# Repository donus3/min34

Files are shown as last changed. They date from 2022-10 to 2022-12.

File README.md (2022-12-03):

# min34

A minimal split keyboard with 34 keys

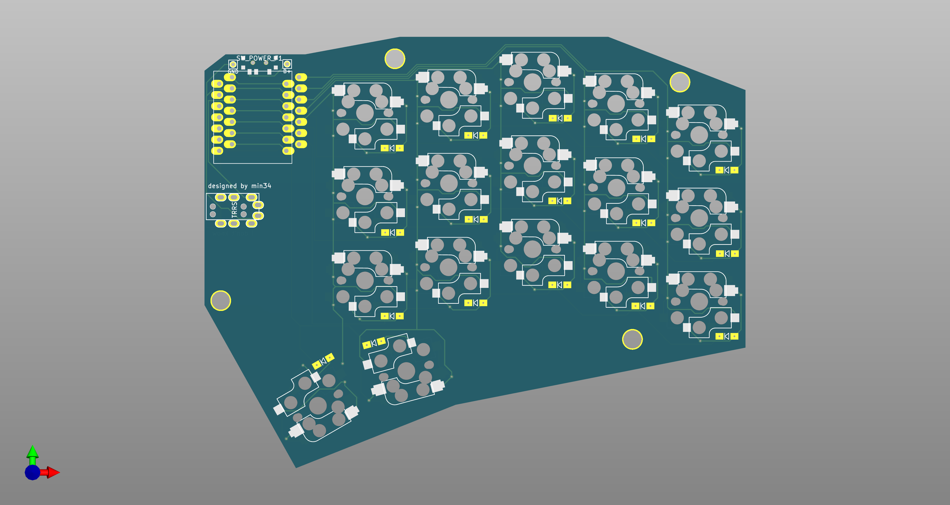
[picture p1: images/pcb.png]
pcb


## Features
 - 34 keys (inspired by Sweep)
 - Support a hotswap switch both MX and Kailh low profile style (inspired by SofleKeyboard)
 - Using seeed studio XIAO series microcontroller which means both wire and wireless are available
 - Support a battery switch on/off if Bluetooth microcontroller is used
 - The PCB is reversible
 - No reset button (it's already on the microcontroller)

I don't focus on adding more features like an OLED display or a rotary encoder because I would like to keep it as simple as possible and I personally
don't use them in my daily life (as a programmer).

## Compnents
 - 2x PCBs (for left and right)
 - 2x seeed studio XIAO compatible boards.
 - 34 switches of MX or Kailh low profile style
 - 34 kailh switch sockets (MX or Kailh low profile)
 - 34 diodes 1N4148W
 - 34 keycaps
 - (optional; only for battery support) 2x power switches (MSK 12C02)
 - (optional; only for wire support) 2x TRRS connectors
 - (optional; only for wire support) 1x TRRS cable
 - 1 USB Cable

## Firmware
Please refer to [min34 zmk config](./firmware)

## Thanks to
 - [SofleKeyboard](https://github.com/josefadamcik/SofleKeyboard)
 - [crkbd](https://github.com/foostan/crkbd)
 - [Slice36](https://github.com/MReavley/Slice36)
 - [Sweep](https://github.com/davidphilipbarr/Sweep)
 - Seeed xiao nrf52840 mcu: https://www.seeedstudio.com/Seeed-XIAO-BLE-nRF52840-p-5201.html
 - Seeed Fusion PCBA service: https://www.seeedstudio.com/pcb-assembly.html
 - Seeed Fusion DIY Mechanical Keyboard contest: https://www.seeedstudio.com/seeed-fusion-diy-xiao-mechanical-keyboard-contest.html

## Gallery

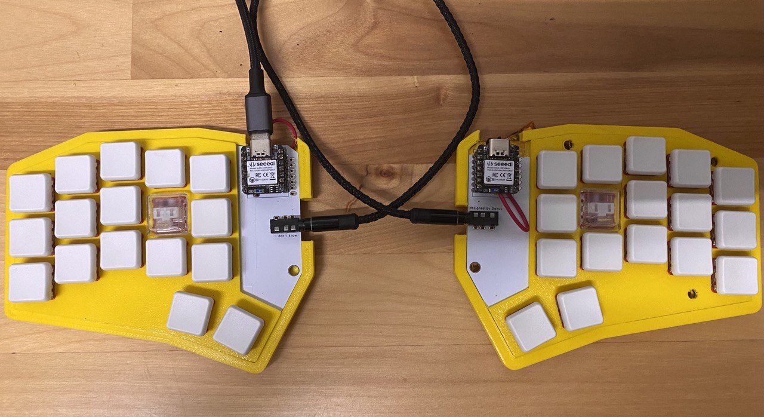
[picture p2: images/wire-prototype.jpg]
min34-wire


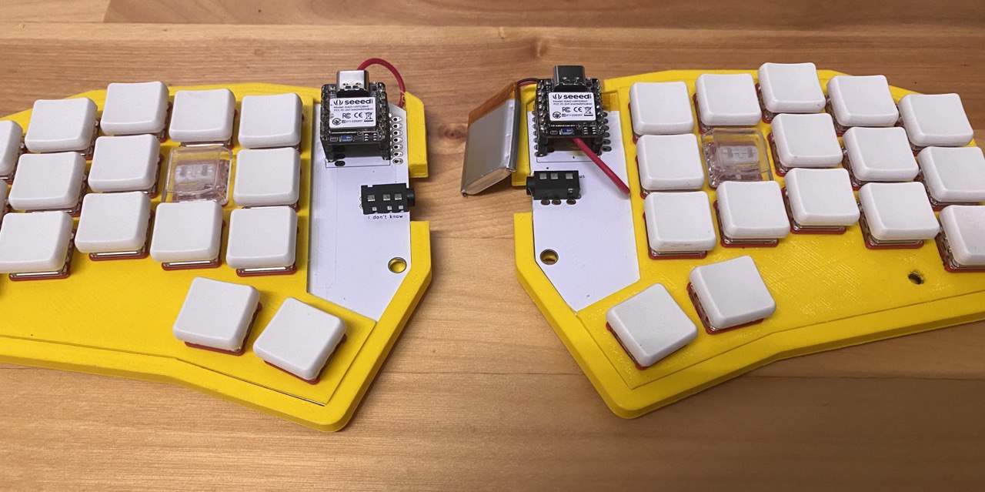
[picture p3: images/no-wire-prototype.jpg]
min34-no-wire


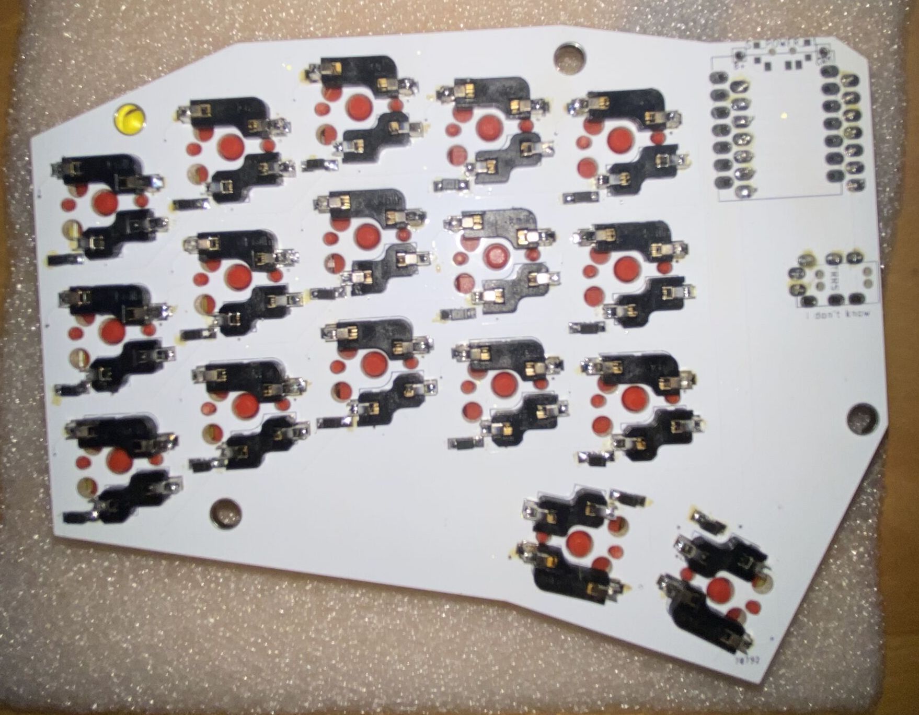
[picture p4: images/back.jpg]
min34-back


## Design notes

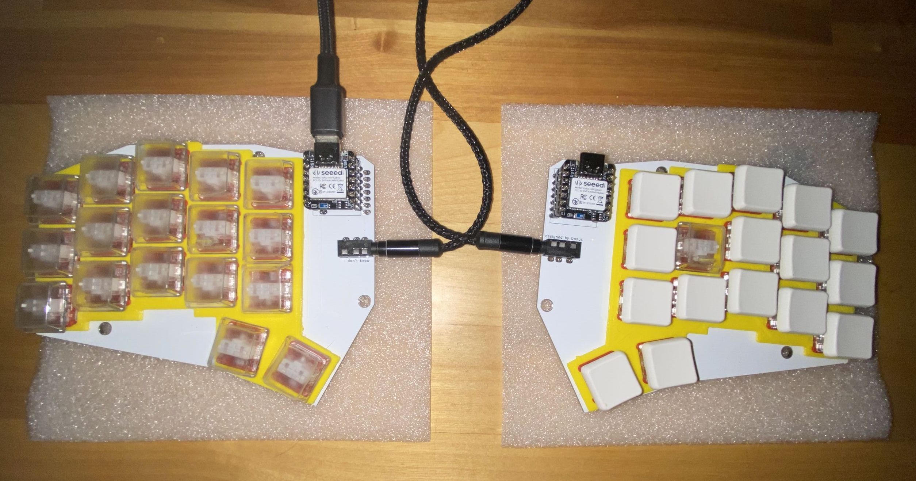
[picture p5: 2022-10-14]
images/wire.jpg

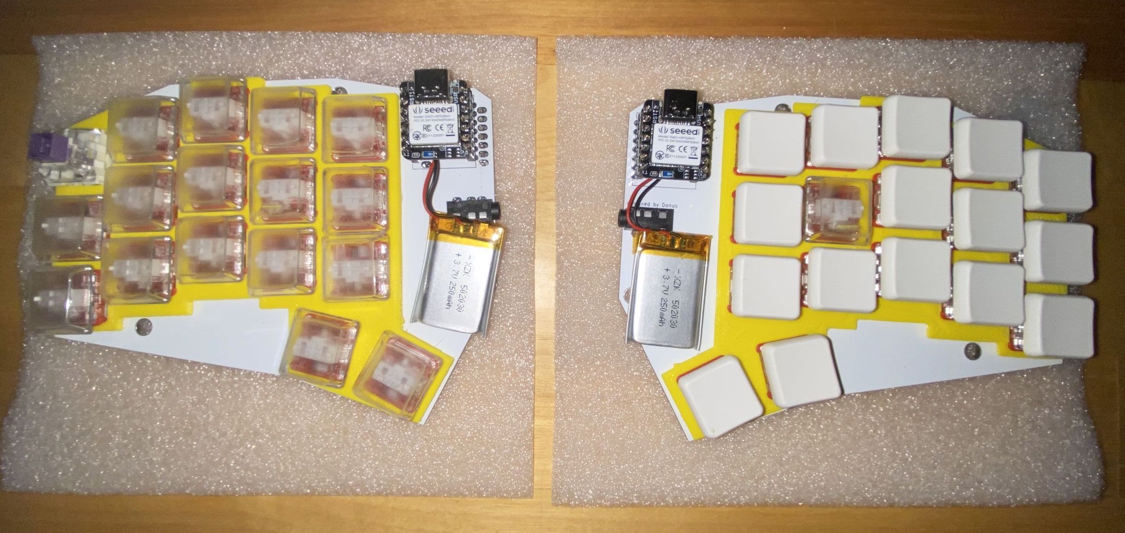
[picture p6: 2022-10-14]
images/wireless.jpg

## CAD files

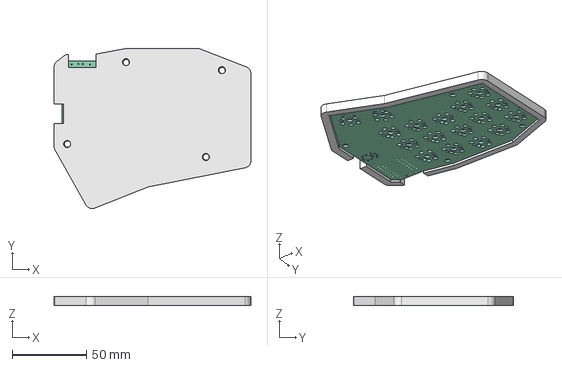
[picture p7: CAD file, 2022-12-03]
3d-print/case.FCStd
133.0 x 108.1 x 6.00 mm
Pcb_3478

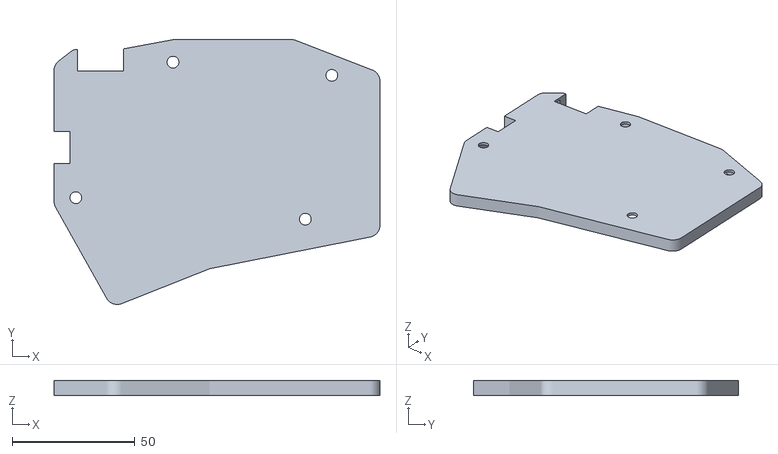
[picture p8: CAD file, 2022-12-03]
3d-print/case-v3.stl
133.0 x 108.1 x 6.00

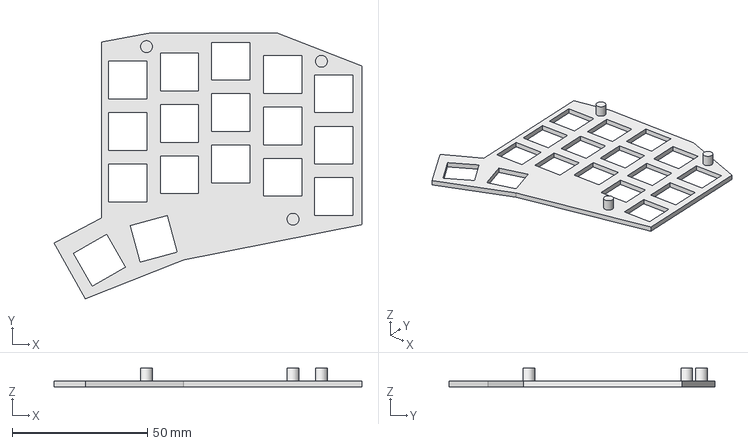
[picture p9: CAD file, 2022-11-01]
3d-print/plate.FCStd
113.8 x 98.1 x 7.00 mm

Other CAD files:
3d-print/plate-v2.stl
3d-print/case.stl
3d-print/plate.stl

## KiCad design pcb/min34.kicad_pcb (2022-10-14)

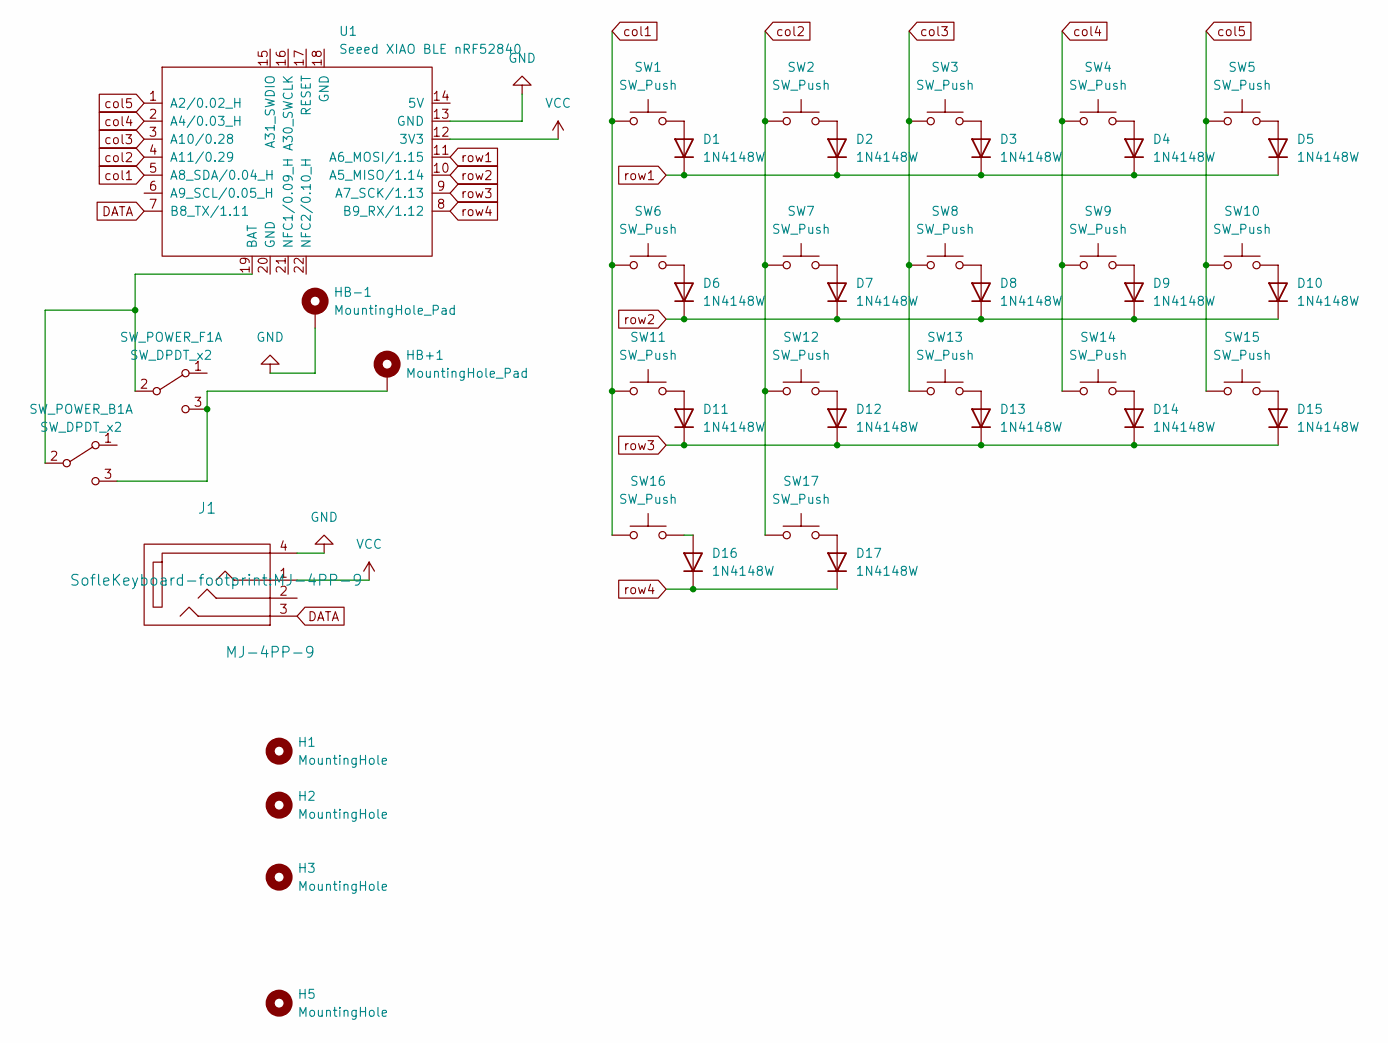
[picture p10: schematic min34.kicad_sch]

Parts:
D1, D2, D3, D4, D5, D6, D7, D8, D9, D10, D11, D12, D13, D14, D15, D16, D17: 1N4148W; Diode_SOD123
H1, H2, H3, H5: MountingHole; HOLE_M2_TH
HB+1: MountingHole_Pad; 1pin_conn
HB-1: MountingHole_Pad; 1pin_conn
J1: MJ-4PP-9
SW1, SW2, SW3, SW4, SW5, SW6, SW7, SW8, SW9, SW10, SW11, SW12, SW13, SW14, SW15, SW16, SW17: SW_Push; CherryMX_KailhLowProfile_Hotswap
SW_POWER_B1: SW_DPDT_x2; SPDT_C128955
SW_POWER_F1: SW_DPDT_x2; SPDT_C128955
U1: Seeed XIAO BLE nRF52840; xiao-ble-tht

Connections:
DATA: J1.3, U1.7 (B8_TX/1.11)
GND: HB-1.1, J1.4, U1.13 (GND); also elsewhere on the board
unnamed: D1.2 (A), SW1.2
unnamed: D2.2 (A), SW2.2
unnamed: D3.2 (A), SW3.2
unnamed: D4.2 (A), SW4.2
unnamed: D5.2 (A), SW5.2
unnamed: D6.2 (A), SW6.2
unnamed: D7.2 (A), SW7.2
unnamed: D8.2 (A), SW8.2
unnamed: D9.2 (A), SW9.2
unnamed: D10.2 (A), SW10.2
unnamed: D11.2 (A), SW11.2
unnamed: D12.2 (A), SW12.2
unnamed: D13.2 (A), SW13.2
unnamed: D14.2 (A), SW14.2
unnamed: D15.2 (A), SW15.2
unnamed: D16.2 (A), SW16.2
unnamed: D17.2 (A), SW17.2
unnamed 19: HB+1.1, SW_POWER_B1.3 (C), SW_POWER_F1.3 (C); also elsewhere on the board
unnamed: SW_POWER_B1.2 (B), SW_POWER_F1.2 (B), U1.19 (BAT)
VCC: J1.1, U1.12 (3V3)
col1: SW1.1, SW6.1, SW11.1, SW16.1, U1.5 (A8_SDA/0.04_H)
col2: SW2.1, SW7.1, SW12.1, SW17.1, U1.4 (A11/0.29)
col3: SW3.1, SW8.1, SW13.1, U1.3 (A10/0.28)
col4: SW4.1, SW9.1, SW14.1, U1.2 (A4/0.03_H)
col5: SW5.1, SW10.1, SW15.1, U1.1 (A2/0.02_H)
row1: D1.1 (K), D2.1 (K), D3.1 (K), D4.1 (K), D5.1 (K), U1.11 (A6_MOSI/1.15)
row2: D6.1 (K), D7.1 (K), D8.1 (K), D9.1 (K), D10.1 (K), U1.10 (A5_MISO/1.14)
row3: D11.1 (K), D12.1 (K), D13.1 (K), D14.1 (K), D15.1 (K), U1.9 (A7_SCK/1.13)
row4: D16.1 (K), D17.1 (K), U1.8 (B9_RX/1.12)

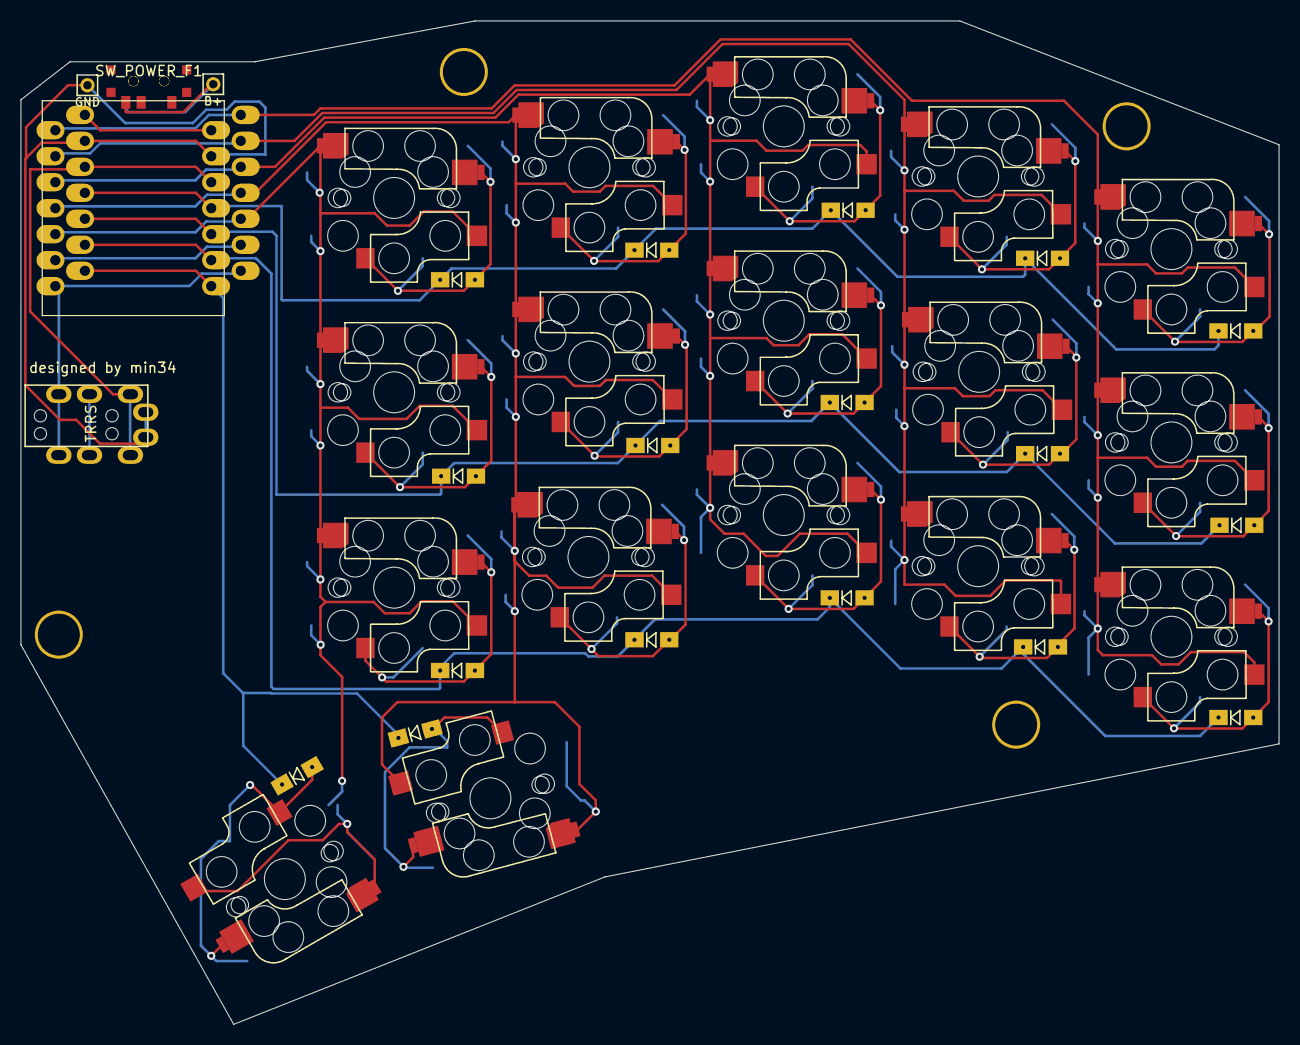
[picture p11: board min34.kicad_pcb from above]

Board: 2 copper layers, 123.0 x 98.1 mm, 44 parts (0 on the bottom side), 31 nets.

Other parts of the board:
B+: MountingHole_Pad; 1pin_conn
GND: MountingHole_Pad; 1pin_conn

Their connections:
GND: GND.1; also elsewhere on the board
unnamed 19: B+.1; also elsewhere on the board

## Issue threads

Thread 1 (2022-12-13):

NOT AN ISSUE: battery wiring question

wesleywchang, 2022-12-13:
Not an issue, but I was wondering if you could share how you wired the batteries. I'm trying to build the wireless version of this board with the Xiao BLE. I don't have a background with electronics so it's a little confusing for me. Sharing images of how the battery is wired would be sufficient.

donus3, 2022-12-15:
This is on my left

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

on my right switch will be placed on the top side of the PCB.

wesleywchang, 2022-12-17:
I was able to get both halves powered wiring this way, but it looks like the power switch does nothing. Is this the same case for you?

donus3, 2022-12-17:
Mine work just fine. You can turn the switch on and put the usb c cable to the XIAO and notice if there is a yellow led turn on. if yes, you've already wire your controller to the PCB correctly. Then, you should check your battery soldering (black cable to the ground and red to the B+). You can post your build pictures here so I can help you validate.

wesleywchang, 2022-12-24:
I was able to get the power switch working; I accidentally bridged the connection while soldering so the battery was in effect always connected. Thanks for the help! This is a really cool design and it's satisfying now that I've worked out all the kinks.

Closed 2022-12-24.

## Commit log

2022-10-14 min34 day 1
    [case.FCStd, min34.kicad_pcb, min34.kicad_sch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]
2022-10-30 update plate 3d model
    [plate.FCStd, plate.stl]
2022-10-30 update case 3d model
    [case.FCStd, case.stl]
2022-11-01 update plate 3d model with screw
    [plate-v2.stl, plate.FCStd]
2022-12-03 3d-print: case support hole
    [case-v3.stl, case.FCStd]
